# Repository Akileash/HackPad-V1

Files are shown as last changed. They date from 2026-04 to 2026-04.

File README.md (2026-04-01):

# HackPad V1

This is my custom macro pad project built around the Seeed Studio XIAO RP2040.  
It has a compact 6-key layout, two rotary encoders, a 0.91" OLED, and RGB lighting.

## Features

- 6 MX-style mechanical switches
- 2 EC11 rotary encoders
- 0.91" I2C OLED display (128x32)
- 6 SK6812 MINI-E RGB LEDs
- Custom 2-layer PCB designed in KiCad
- Custom case designed in CAD
- KMK-based firmware configuration

## Project Images

### Overall HackPad

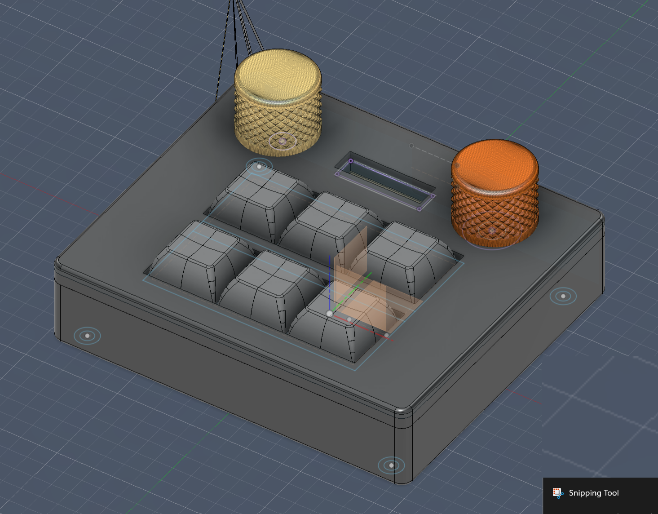
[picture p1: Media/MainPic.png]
Overall HackPad


### Parts

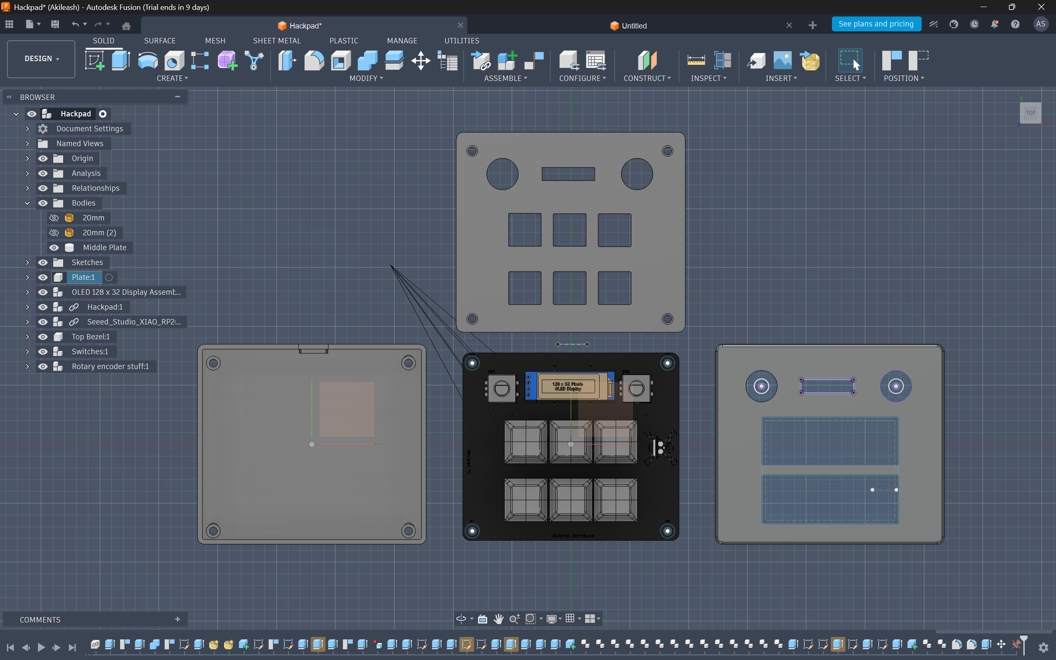
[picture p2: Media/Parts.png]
Parts


### PCB

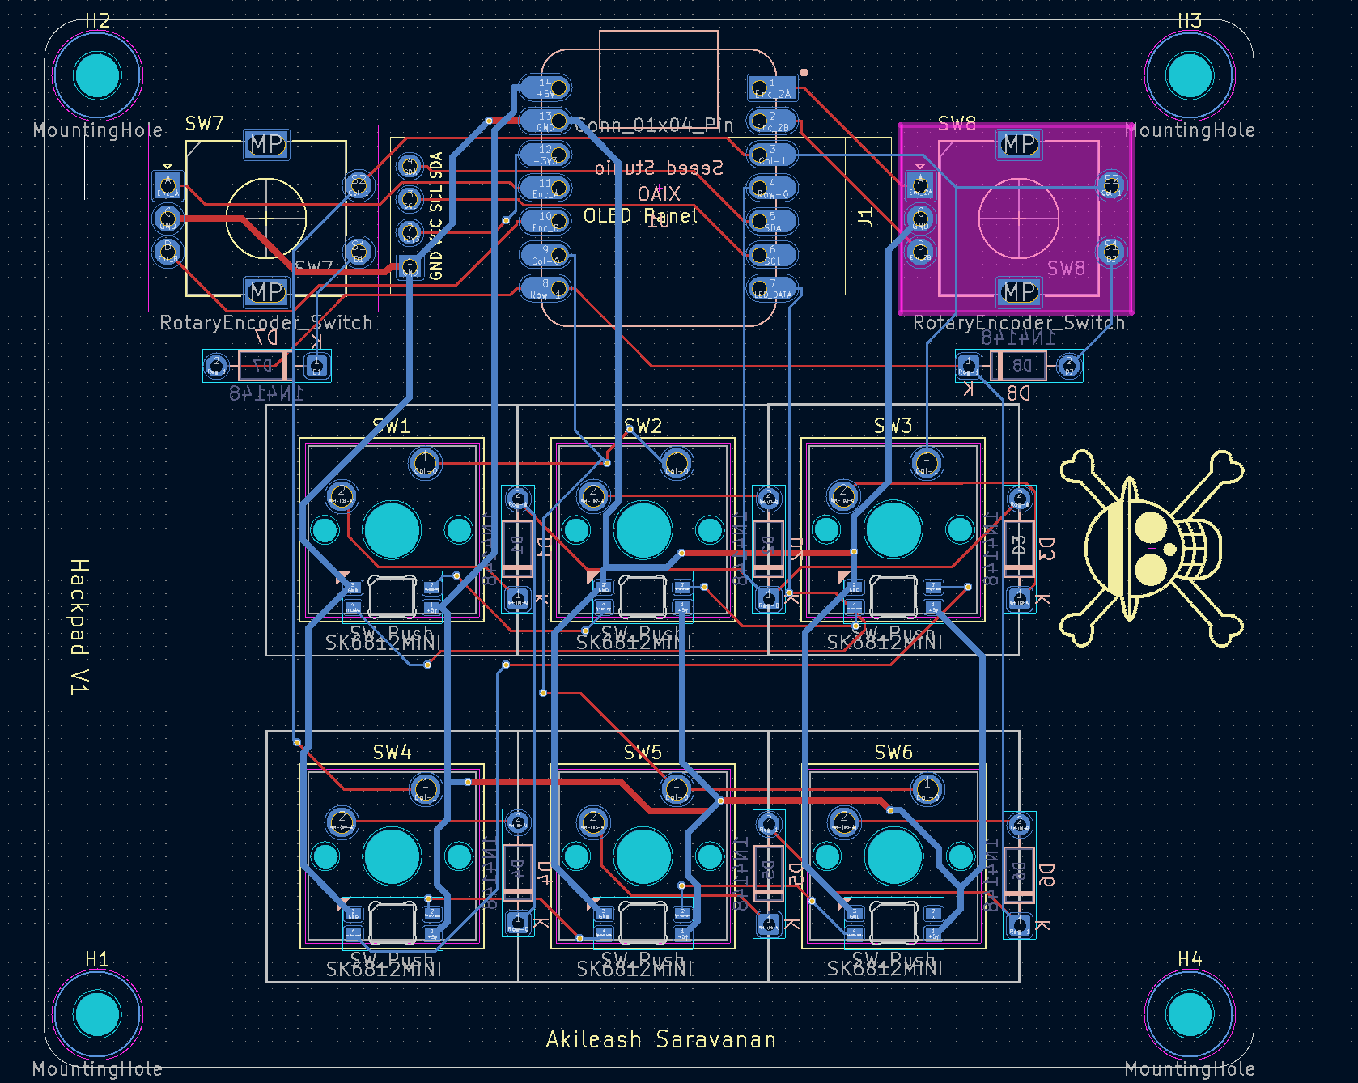
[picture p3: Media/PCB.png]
PCB


### Schematics

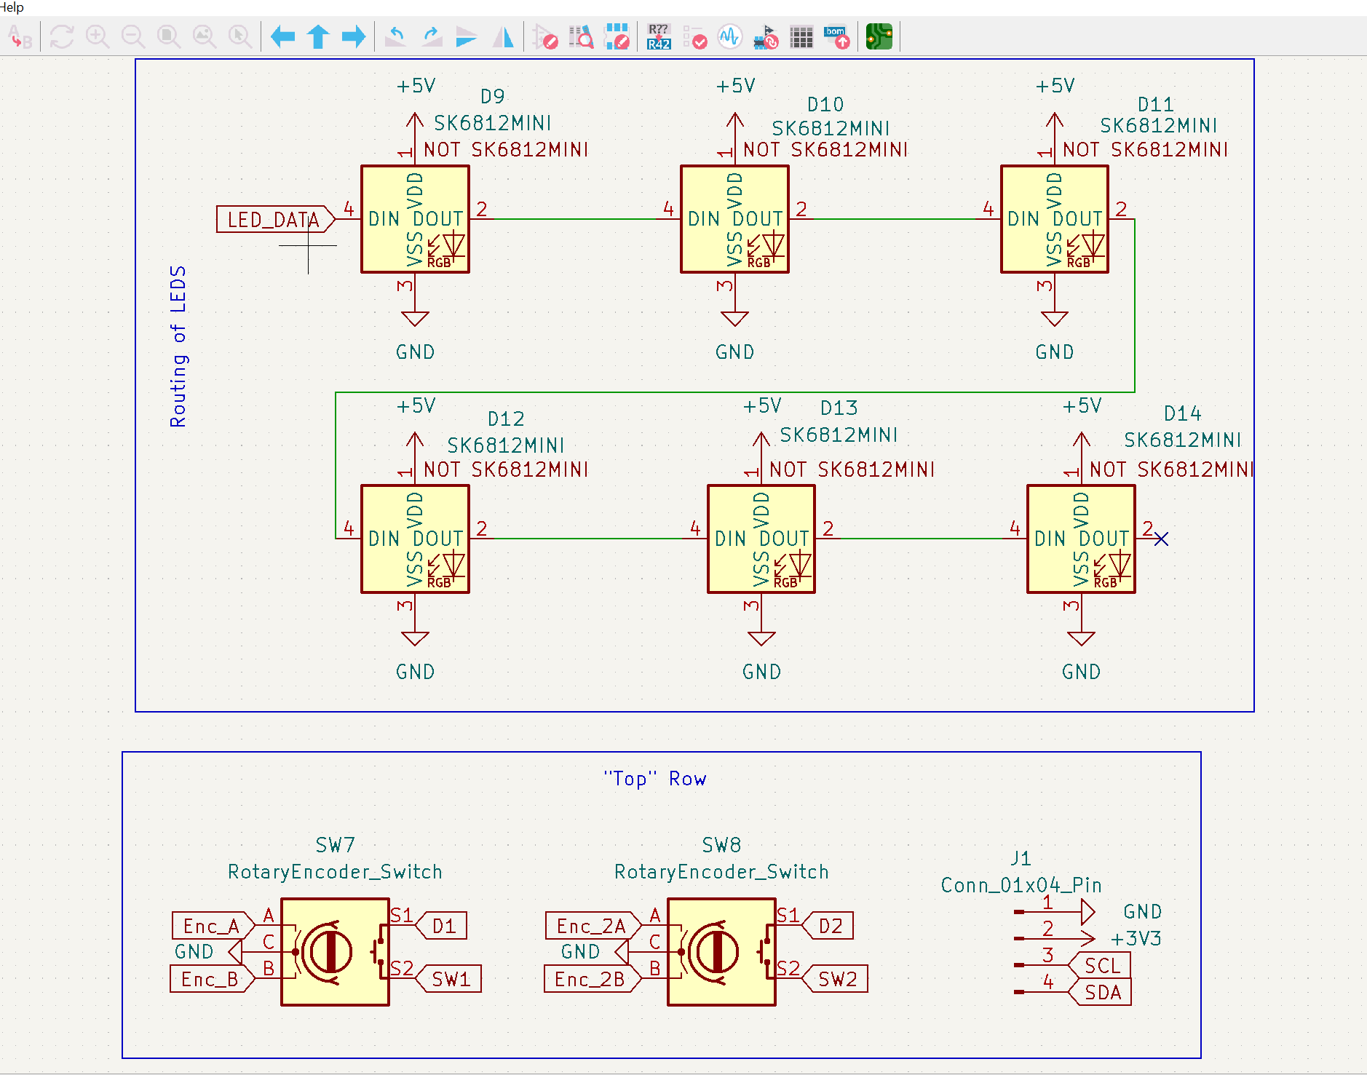
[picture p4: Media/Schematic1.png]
Schematic 1

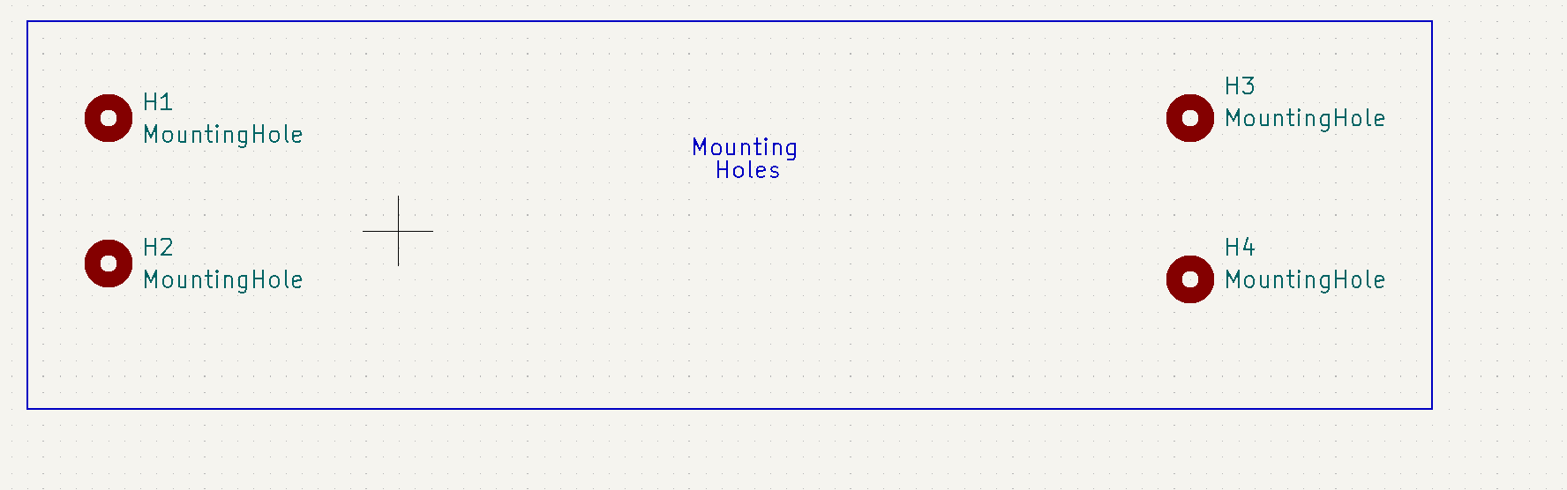
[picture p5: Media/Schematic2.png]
Schematic 2

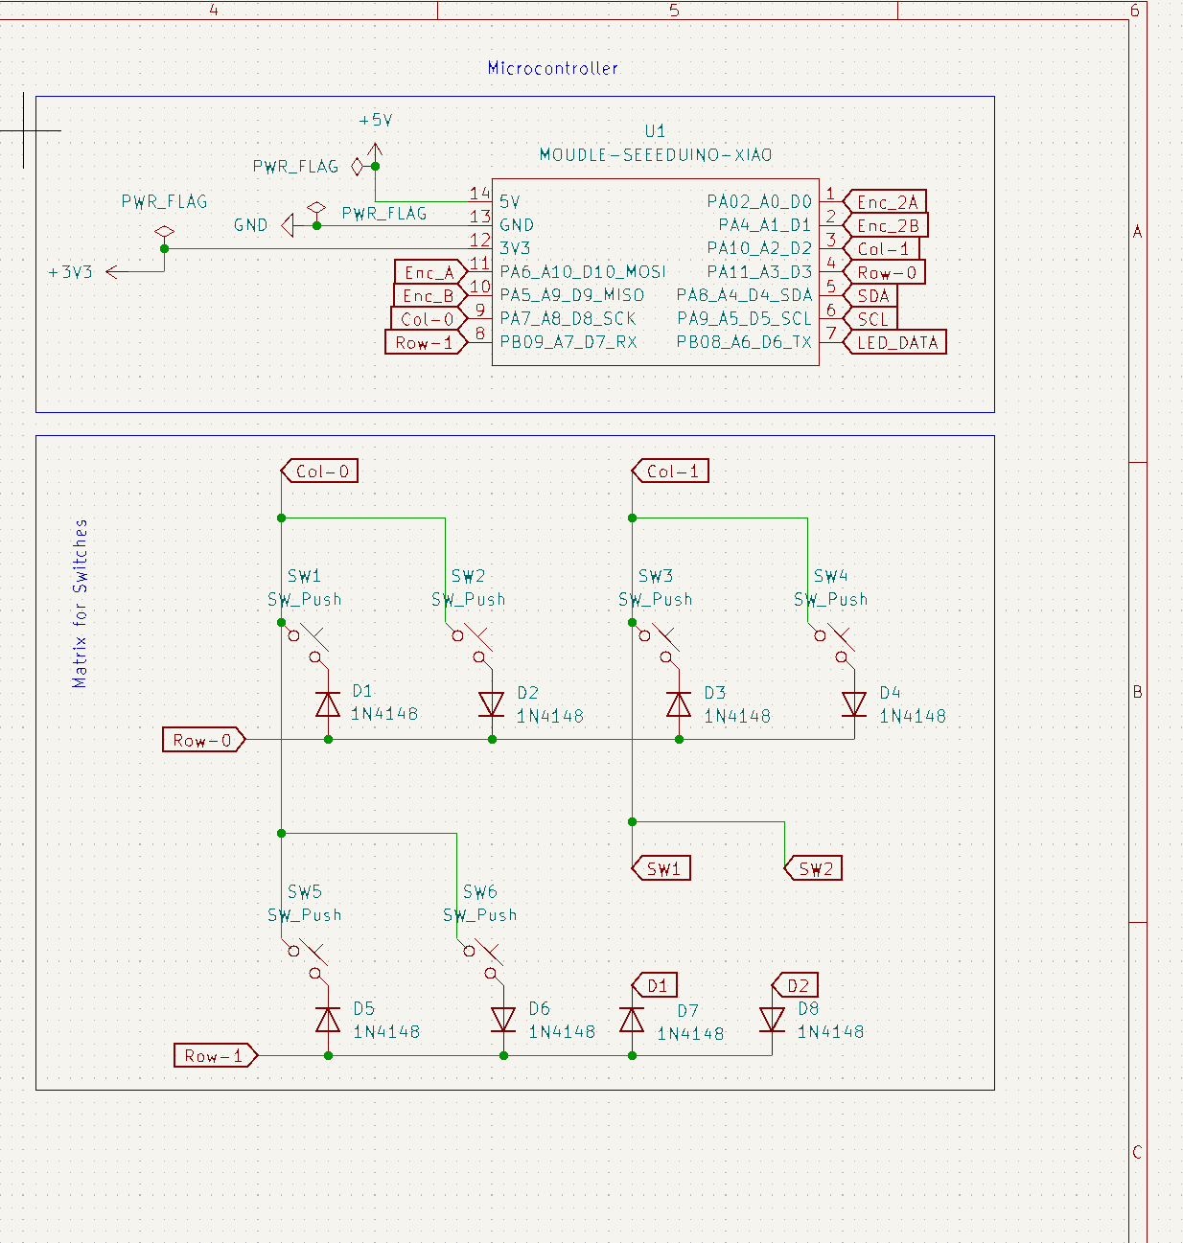
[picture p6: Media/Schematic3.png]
Schematic 3


## Bill of Materials (BOM)

| Item | Quantity | Description |
| :--- | :---: | :--- |
| MCU | 1 | Seeed Studio XIAO RP2040 (Unsoldered) |
| Switches | 6 | MX-Style Mechanical Switches |
| Keycaps | 6 | White Blank DSA Profile Keycaps |
| Encoders | 2 | EC11 Rotary Encoders |
| OLED Display | 1 | 0.91" I2C OLED (Pinout: GND-VCC-SCL-SDA) |
| Diodes | 8 | 1N4148 Through-hole Diodes |
| LEDs | 6 | SK6812 MINI-E RGB NeoPixels |
| Screws | 4 | M3x16mm Socket Head Cap Screws |
| Inserts | 4 | M3 Brass Heat-Set Inserts (5mm OD, 4mm Length) |
| PCB | 1 | Custom 2-Layer Hackpad PCB |
| Feet | 4 | Adhesive rubber bumpons (screw size may be 3x20 if needed) |

## Firmware

Firmware is in `Firmware/main.py`. Right now it is set up for:

- 6-key macro layout
- dual encoder input
- OLED output
- onboard RGB effects

## Repository Structure

- `Firmware/` - KMK firmware
- `PCB/` - KiCad files
- `CAD/` - complete CAD model
- `Production/Case/` - case production parts
- `Media/` - README images

## Notes

Images used in this README are stored in `Media/`:

- `MainPic.png`
- `Parts.png`
- `PCB.png`
- `Schematic1.png`
- `Schematic2.png`
- `Schematic3.png`

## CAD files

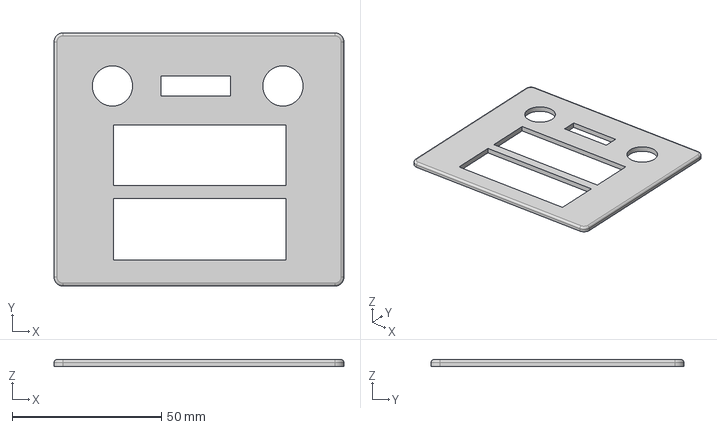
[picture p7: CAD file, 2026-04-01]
Production/Case/TopPart.step
97.2 x 84.9 x 2.25 mm

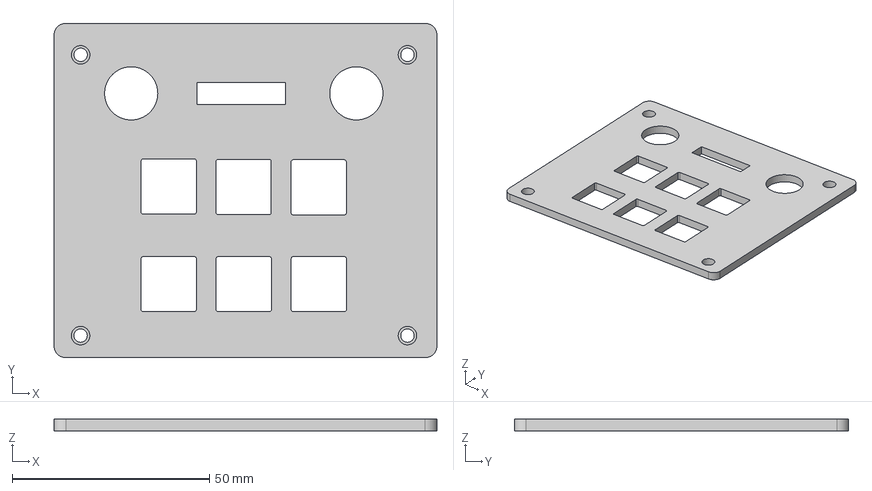
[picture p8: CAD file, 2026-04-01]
Production/Case/MiddleBracket.step
97.2 x 84.9 x 3.00 mm

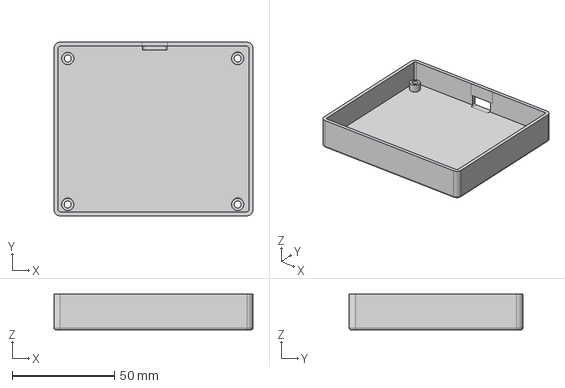
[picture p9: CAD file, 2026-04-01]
Production/Case/Bottom Plate.step
97.2 x 84.8 x 17.5 mm

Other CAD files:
Production/Case/RotaryEncoderDial.step

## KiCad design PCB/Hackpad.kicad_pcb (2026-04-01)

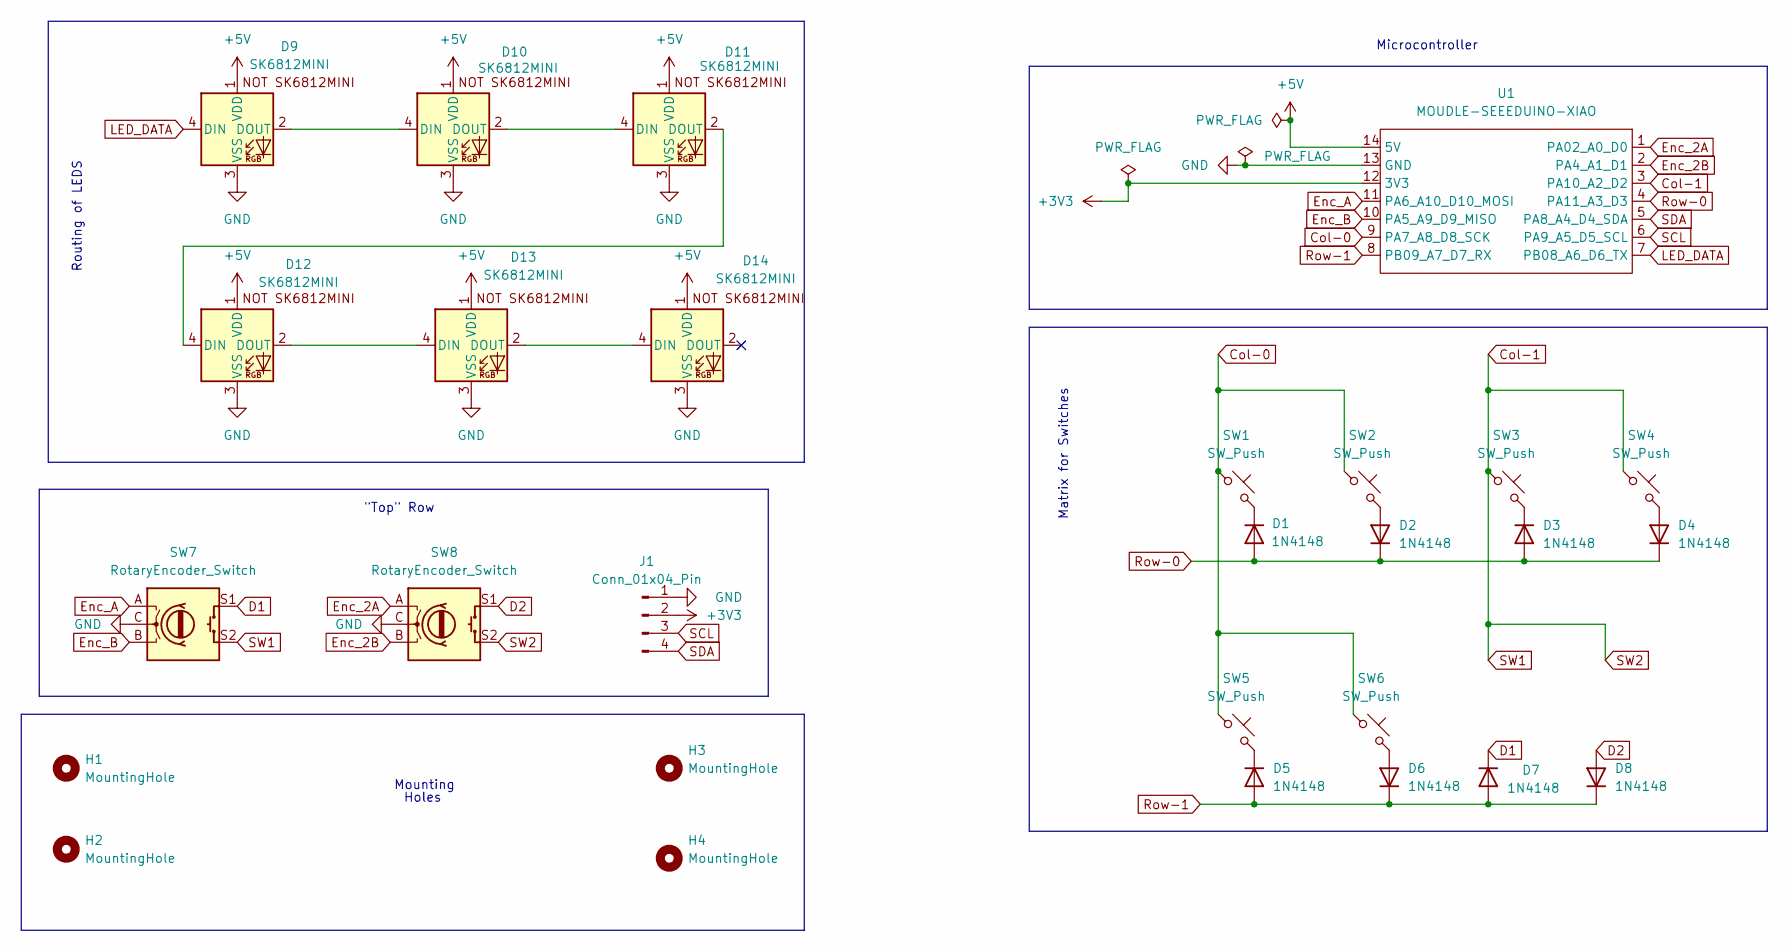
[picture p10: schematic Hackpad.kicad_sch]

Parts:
D1, D2, D3, D4, D5, D6, D7, D8: 1N4148; D_DO-35_SOD27_P7.62mm_Horizontal
D9, D10, D11, D12, D13, D14: SK6812MINI; MX_SK6812MINI-E_REV
H1, H2, H3, H4: MountingHole; MountingHole_3.2mm_M3
J1: Conn_01x04_Pin; SSD1306-0.91-OLED-4pin-128x32
SW1, SW2, SW3, SW4, SW5, SW6: SW_Push; SW_Cherry_MX_1.00u_PCB
SW7, SW8: RotaryEncoder_Switch; RotaryEncoder_Alps_EC11E-Switch_Vertical_H20mm
U1: MOUDLE-SEEEDUINO-XIAO; XIAO-Generic-Hybrid-14P-2.54-21X17.8MM

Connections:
+3V3: J1.2, U1.12 (3V3)
+5V: D9.1 (VDD), D10.1 (VDD), D11.1 (VDD), D12.1 (VDD), D13.1 (VDD), D14.1 (VDD), U1.14 (5V)
Col-0: SW1.1, SW2.1, SW5.1, SW6.1, U1.9 (PA7_A8_D8_SCK)
Col-1: SW3.1, SW4.1, SW7.S2, SW8.S2, U1.3 (PA10_A2_D2)
D1: D7.1 (K), SW7.S1
D2: D8.2 (A), SW8.S1
Enc_2A: SW8.A, U1.1 (PA02_A0_D0)
Enc_2B: SW8.B, U1.2 (PA4_A1_D1)
Enc_A: SW7.A, U1.11 (PA6_A10_D10_MOSI)
Enc_B: SW7.B, U1.10 (PA5_A9_D9_MISO)
GND: D9.3 (VSS), D10.3 (VSS), D11.3 (VSS), D12.3 (VSS), D13.3 (VSS), D14.3 (VSS), J1.1, SW7.C, SW8.C, U1.13 (GND)
LED_DATA: D9.4 (DIN), U1.7 (PB08_A6_D6_TX)
unnamed: D1.1 (K), SW1.2
unnamed: D2.2 (A), SW2.2
unnamed: D3.1 (K), SW3.2
unnamed: D4.2 (A), SW4.2
unnamed: D5.1 (K), SW5.2
unnamed: D6.2 (A), SW6.2
unnamed: D9.2 (DOUT), D10.4 (DIN)
unnamed: D10.2 (DOUT), D11.4 (DIN)
unnamed: D11.2 (DOUT), D12.4 (DIN)
unnamed: D12.2 (DOUT), D13.4 (DIN)
unnamed: D13.2 (DOUT), D14.4 (DIN)
Row-0: D1.2 (A), D2.1 (K), D3.2 (A), D4.1 (K), U1.4 (PA11_A3_D3)
Row-1: D5.2 (A), D6.1 (K), D7.2 (A), D8.1 (K), U1.8 (PB09_A7_D7_RX)
SCL: J1.3, U1.6 (PA9_A5_D5_SCL)
SDA: J1.4, U1.5 (PA8_A4_D4_SDA)

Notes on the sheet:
Mounting
Microcontroller
Matrix for Switches
Routing of LEDS
Holes
"Top" Row

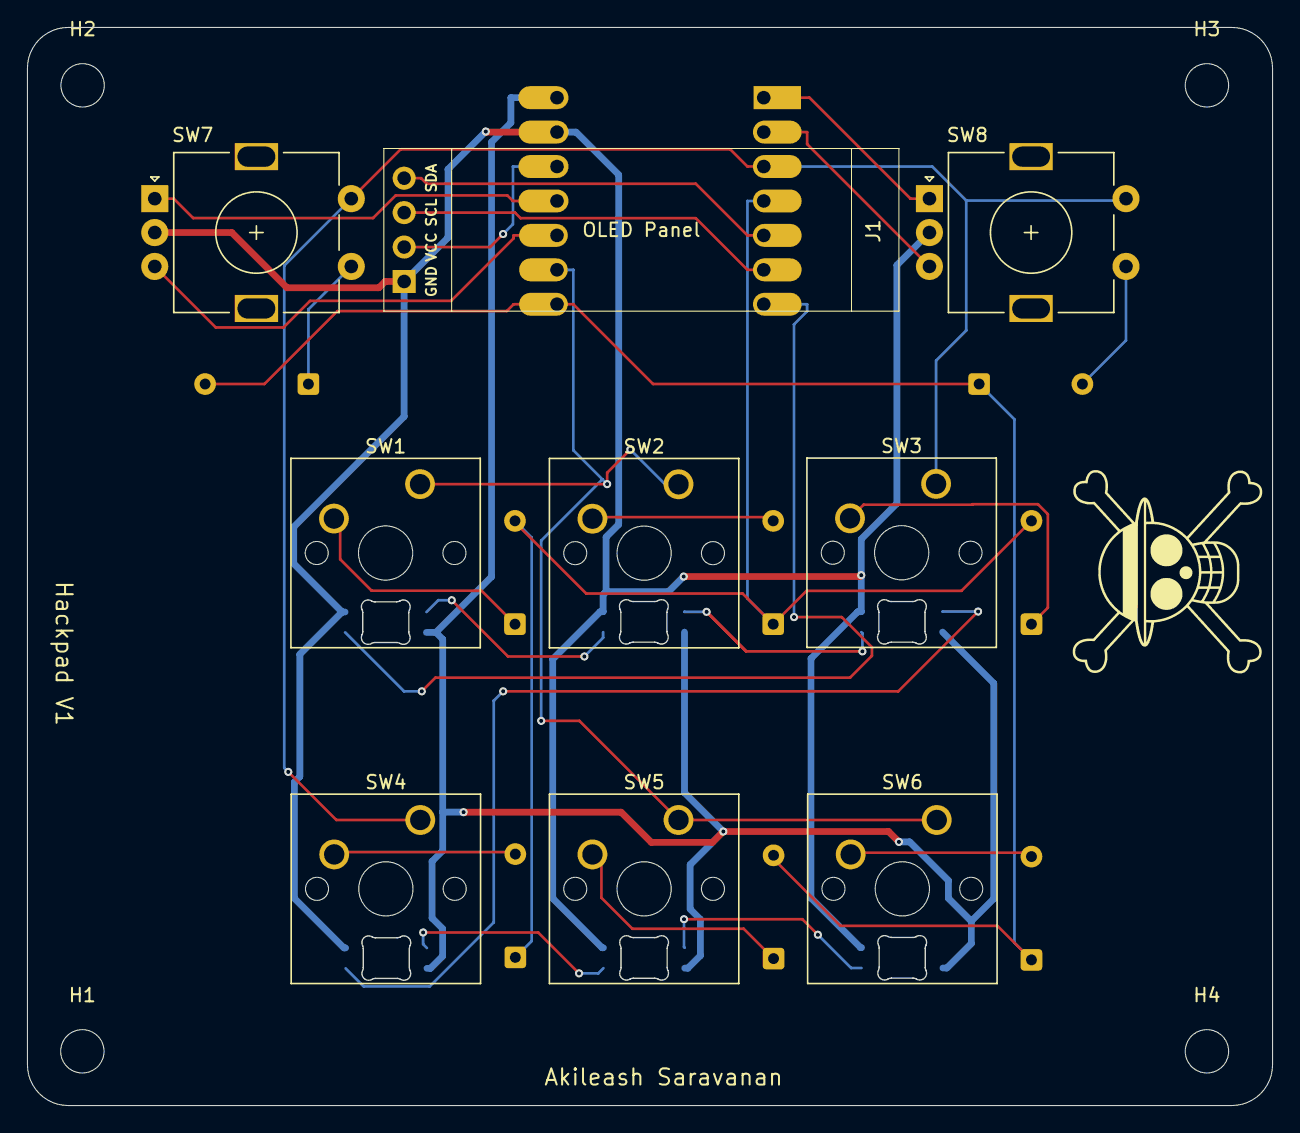
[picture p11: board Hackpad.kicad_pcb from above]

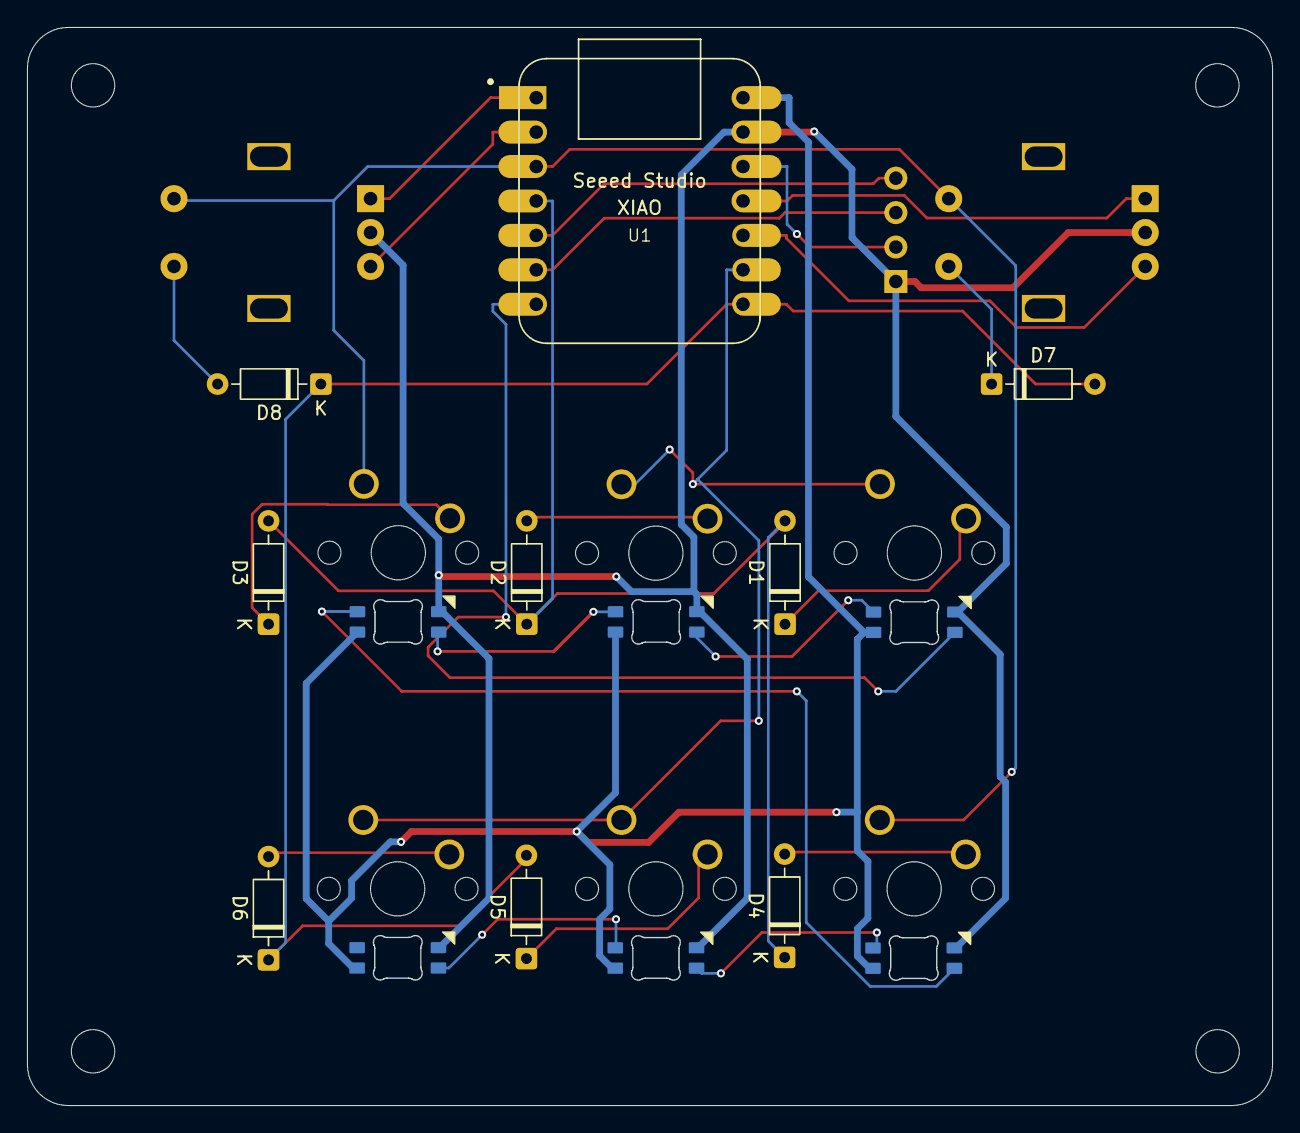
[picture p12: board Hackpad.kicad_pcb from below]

Board: 2 copper layers, 91.8 x 79.5 mm, 28 parts (9 on the bottom side), 27 nets.

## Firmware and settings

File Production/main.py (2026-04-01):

# AkiPad - KMK Firmware
# Akileash Saravanan

import board
import busio
import digitalio

from kmk.kmk_keyboard import KMKKeyboard
from kmk.keys import KC
from kmk.scanners.keypad import KeysScanner
from kmk.modules.encoder import EncoderHandler
from kmk.extensions.rgb import RGB
from kmk.extensions.display import Display, TextEntry
from kmk.extensions.display.ssd1306 import SSD1306Driver

keyboard = KMKKeyboard()

# ── Matrix pins ──────────────────────────────────────────────
# Duplex matrix
# Col-0 = D8 = GP2, Col-1 = D2 = GP28
# Row-0 = D3 = GP29, Row-1 = D7 = GP1
keyboard.col_pins = (board.D8, board.D2)
keyboard.row_pins = (board.D3, board.D7)
keyboard.diode_orientation = None  # duplex matrix handles this

# ── Keymap ────────────────────────────────────────────────────
# Layout:
# [ Play/Pause ] [ Next Track ] [ Mute ]
# [ Copy       ] [ Paste      ] [ Undo ]
keyboard.keymap = [
    [
        KC.MPLY,  KC.MNXT,  KC.MUTE,
        KC.COPY,  KC.PASTE, KC.UNDO,
    ]
]

# ── Encoders ─────────────────────────────────────────────────
# Encoder 1: Enc_A = D10 = GP3, Enc_B = D9 = GP4
# Encoder 2: Enc_2A = D0 = GP26, Enc_2B = D1 = GP27
encoder_handler = EncoderHandler()
encoder_handler.pins = (
    (board.D10, board.D9, None, False),   # Encoder 1
    (board.D0,  board.D1, None, False),   # Encoder 2
)
encoder_handler.map = [
    # Layer 0
    (
        (KC.VOLD, KC.VOLU),  # Encoder 1: Volume
        (KC.VOLD, KC.VOLU),  # Encoder 2: Volume
    ),
]
keyboard.modules.append(encoder_handler)

# ── RGB LEDs ─────────────────────────────────────────────────
# LED_DATA = D6 = GP0
rgb = RGB(
    pixel_pin=board.D6,
    num_pixels=6,
    hue_default=0,
    sat_default=255,
    val_default=128,
    animation_mode=AnimationModes.BREATHING,
)
keyboard.extensions.append(rgb)

# ── OLED Display ─────────────────────────────────────────────
# SDA = D4 = GP6, SCL = D5 = GP7
i2c_bus = busio.I2C(board.D5, board.D4)

display = Display(
    display=SSD1306Driver(i2c=i2c_bus, device_address=0x3C),
    entries=[
        TextEntry(text='  AkiPad  ', x=0, y=0),
        TextEntry(text='----------', x=0, y=8),
        TextEntry(text='Akileash  ', x=0, y=16),
        TextEntry(text='Saravanan ', x=0, y=24),
    ],
    width=128,
    height=32,
)
keyboard.extensions.append(display)

# ── Start ─────────────────────────────────────────────────────
if __name__ == '__main__':
    keyboard.go()
